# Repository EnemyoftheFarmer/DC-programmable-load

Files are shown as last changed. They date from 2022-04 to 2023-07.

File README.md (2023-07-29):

# Attention
You will need Horizon EDA to view the PCB files.
## Modular Electronic DC Load
#### Motivation
This project will implement a modular 450W DC programmable load. A programmable load is a piece of equipment used to test power supplies, batteries and more. It can also be used to simulate load types or effectively act as a large linear regulator. The motivation came from another project where I needed to measure the efficiency of a boost-buck converter. I needed a high power DC load FAST. This lead to the stupid requirement that I be able to regulate mA and A in the same control loop using no ranging tricks. This had some dumb and interesting consequences in my selection of components.

<figure>
  Bla
  <figcaption>
    Figure 1: DC Load Use Diagram.
    <br>
    An electronic load can be used to test many devices. The most common uses include testing the efficiency of power supplies as well measuring the capacity of batteries. In this example we can see a power supply      being tested for efficiency by measuring input and output power.
  </figcaption>
</figure>

#### Architecture
The architecture is a straightfoward current sink. An opamp drives a MOSFET's gate input until the feedback voltage generated over a current shunt is equal to its set voltage which is derived from a DAC. For the typical DC load functions expected, such as constant power or constant resistance, a microcontroller will calculate the required DAC output voltage.

Three separate PCBs will conprise the system. The logic board will contain all the connectors to the other PCBs and will mount a PICO board for the first revision. Later the RP2040 will be integrated into the logic board. A second board will provide the two voltage rails needed for the DAC and OPAMPs. Power for this board needs to come from an isolated PSU in order to prevent ground loops forming between the system supply and the DUT(device under test). It is yet to determine if it is easier to buy an isolated 12V supply or to use an unisolated 12V and a 12V to 5V on board isolated converter that powers everything except the fans. In the latter case some sort of isolation between the MCU and the 12V fans would need to be added in order to control them. 

Finally, the meat and potatoes of the system is the analog control board. It contains the opamp, DAC, ADC, current shunt, and the MOSFET gate control output. It is intended to be modular such that the system can theorectically be expanded as much as one desires. I have yet to have an idea how to deal with this in software, and in reality there is a practical limit since the DAC is currently SPI controled which means that there needs to be a CS(chip select) pin for each analog control board. Additionally, the ADC has only four adresses it can use, which also limits the expandability. It might be easiest to make the system top out at two or four channels each, and then allow the systems to be slaved to each other over SCPI or something. 

System_Architecture drawio

#### Interface
A rotary encoder is the sole user input for now. A couple of additional hardware buttons would be nice like OUTPUT on/off or mode switching. This area has the most to be decided and is also of lowest priority since it is easy to change without ordering new hardware.

## Component Selection
#### MOSFET
To keep things simple, it uses a single IXYS IXTN200N10L2 Linear MOSFET instead of paralleling many MOSFETs. Most modern MOSFETs are not very well suited to linear operation and many datasheets do not even characterize the DC SOA. One of the reasons is that modern MOSFETs are generally composed of many parallel MOSFETs internally and this can result in hot spotting. The IXYS Linear MOSFETs are specifically built and tested to avoid this. For a one off or hobbyist 
load, it is easier to pay (or sample) the much higher price for a few mosfets that 
are precharacterized and will reliably give you 450W of dissapation. The alternative would be to
buy many opamps and mosfets to divide the load. Assuming that a typical
TO220 package run at a conservative 10W, you would need to make sure to get the price per channel down to around a dollar to make it cost competitive. Definitely achievable, but now 45 TO220s need to be mounted. Additionally, the MOSFET is easily water coolable and already isolated. 
However, I am investigating alternatives since when this project originally started before the silicon shortage, the MOSFET could be bought for a hair under 30$ on mouser. It now costs around 50$... Luckily for the individual it can be sampled so a student or hobbyist may be in luck and won't have to pay a dime if they head over to littlefuse's sample center. It may also be possible to buy directly from littlefuse for a far lower price. One alternative so far is the FDL100N50F, which has a DC SOA of 2.5kW. It seems a little unbelievable to get so much power dissapation in a TO-264 package but who knows. It does have an claimed incredible thermal resistance of just 0.05K/W. The good news is that it only costs 10$ per device and if we run it a very conservative 1/5 of claimed SOA, we still get 500W of power. The biggest downside is no screw terminals and no isolation. The lack of isolation means multiple mosfets cannot be attached to the same heatsink since if one mosfet is on but another off, there is a potential difference between the two. Normally this should not be a problem since the leakage current would be small. However, it would cause a problem when water cooling since electroylsis between the two potential would now take place resulting in corrosion taking place over time. 
#### OPAMP 
The control loop is formed by a very cool ADA4523-1 zero drift opamp. Its 4uV of offset means only 4mA of offset current using a 1 milliohm current shunt. Zero drift is very important since any temperature change will result in the offset current changing noticiably due to the low shunt resistance. It also has a very low 88nV p-p 0.1 to 10Hz input noise which is pretty much all we care about in our DC load anyways. This begs the question why we need a low noise percision op amp for a DC load and the answer is I wanted to be able to set mAs on a 1 milliohm shunt. We need a 1 milliohm shunt because I wanted to sink at least 40A which would mean a 2.5W dissapted in the shunt resistor. An alternative but more expensive part is OPA189.   
#### DAC
My requirement to set mA to A in one range meant that a DAC better than the typical 12 bit DAC is required. I also wanted it to be bipolar in case I needed to set negative voltage to calibrate out the OPAMP offset. In the first revision this accomplished by using a second DAC channel to generate an offset. But since that DAC needed to be replaced anyways, the opportunity was present to simplfy the design and increase laziness. The AD5761R was chosen because it was the cheapest, 16bit, bipolar, TSSOP, and available to sample from Analog Devices DAC.
#### Microcontroller
A raspberry PICO is the brain of the system. The first most important reason is I did not want to use Arduino for once and the documentation for the PICO was very good. Addtionally, its cheap, fast, and wasn't hit by the silicon shortage. I didn't want to integrate an STM32 or the like knowing that no one else could reimplement this system because of supply disruption. 
#### ADC
An ADS1115 was chosen to be the ADC. Its classic, 16 bit and I had it laying around. My only question is if it should be replaced with an ADS1118 so one bus can be eliminated and the system tranisitioned completely to SPI. A modified version of [Elektor Labs](https://github.com/ElektorLabs/ads1115-driver) ADS1115 driver is used to interface with it.
#### Cooling
The cooling system consists primarly out of PC water cooling parts. The radiator is 240mm by 40mm. The resovoir and pump are also just cheap amazon PC water cooling components. In the test runs so far, it seems to be to able to keep the mosfet at around 65 degrees while under 450W of load with the fans at full tilt after the water hits saturation. That puts the junction temp. at ~133 degrees. While still under the TJ_MAX of 150 degrees, it is not clear how this impacts the lifespan of the device, especially considering its high price. Either the cooling capacity needs to be upgraded, the load run less hard, or tests/enquires made to see if its something to worry about. There are tentative plans to attach a thermister to the MOSFET and write some code to make sure that TJ_MAX is never exceeded. 

## PCB Layout and Noise Considerations
Something interesting is that thermal emf had to be considered in the design. Of course it is my fault for expecting to regulate mA and A all in one current shunt but it provided an interesting opportunity to learn. This meant thermal gradients and changes in temperature had to be prevented. The first was to cut an a pair of slots in the PCB so that the heat from the current shunt can not travel to the rest of the components so easily in order to to reduce drift or noise caused by the heat. Then  all critical resistors were aligned perpendicular to the expected thermal gradient since that would mean a much smaller gradient across said resistors. Additionally, there is a method to layout resistors such that thermal emf should cancel. 

thermalemf
 
These last two methods I read about from application note AN1258 from Microchip. Futhermore, in order to avoid Johnson noise, which is thermal noise that is proportional to bandwidth and resistor size, the critical resistors were chosen to be 10 ohms. That puts the resistor noise levels in the 10s of nV for a bandwidth of 1000Hz. This means that so far the theorectical dominant noise source is either the control op amp input noise or the DAC output noise.

## Problems Encountered and Summary so Far
I am quite amazed at how well the load works. Regulating down to 10mA seems no issue which represents a DC level of 10uV. The mA regulation will be implemented soon, but the author was too lazy to modify the software so far. The current is stable down the mA range and noise occurs in the 100s of uA range which would indicate a noise level of 100s of nVs. The current guess is that the op amp input noise, which is 88nV p2p, is the bottleneck. A lower noise but higher drift LT6018 may be tested to see if improvements could be made, even if unnesscary since the requirement was already achieved, as a way to test this theory. The current was measured using the mA range on a Fluke 87V DMM.  

At this stage, the next step is to finalize the analog board layout, complete the logic board layout, and populate the split rail PSU pcb. Additionally, a prototype front panel using an aluminum pcb will be made.
## Prototype Photo





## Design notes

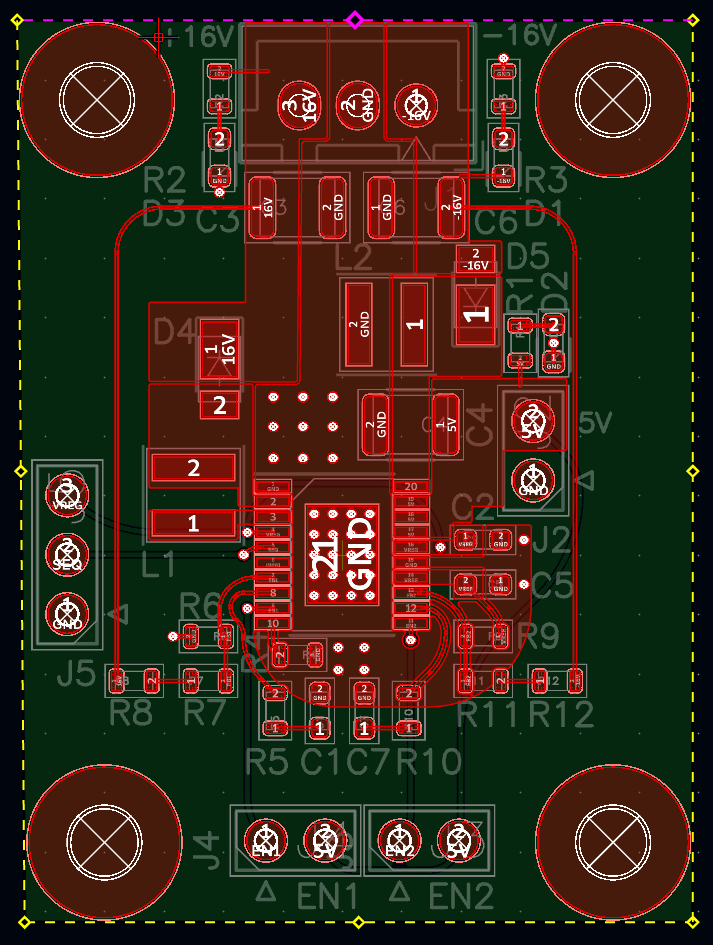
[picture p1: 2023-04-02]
Split_Rail_PSU_PCB.PNG

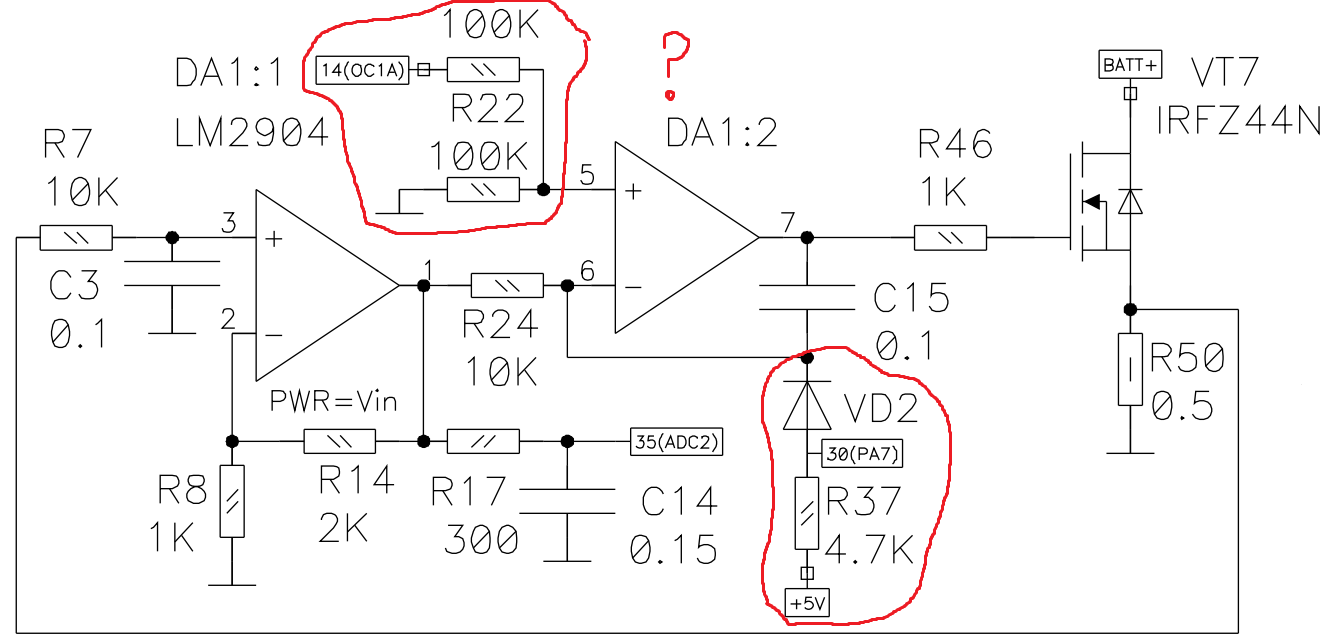
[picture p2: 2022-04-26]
IMAXB6.png

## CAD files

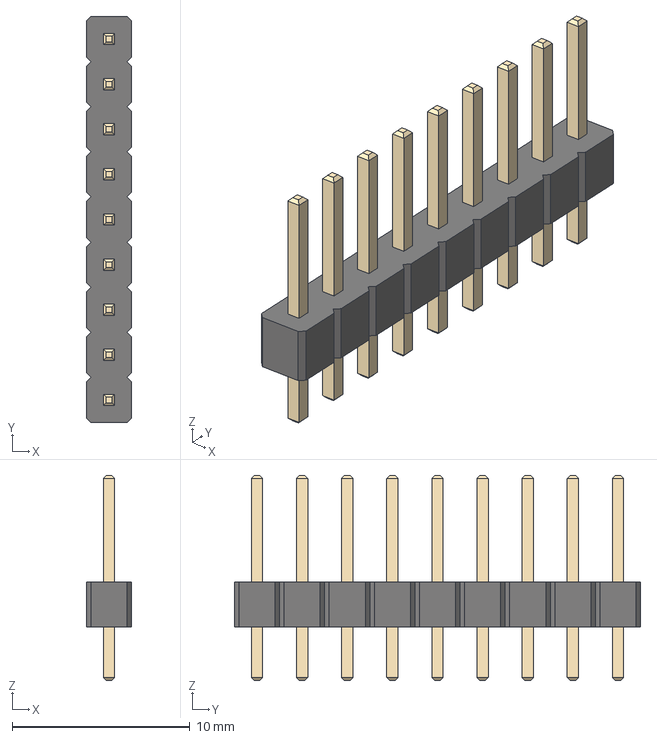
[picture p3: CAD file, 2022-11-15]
Eload-Horizon/Controller/pool/3d_models/cache/6d752bc3-29b3-45df-8cf2-1e3aacefbcc6/3d_models/connector/header/2.54mm/PinHeader_1x09_P2.54mm_Vertical.step
2.54 x 22.9 x 11.5 mm

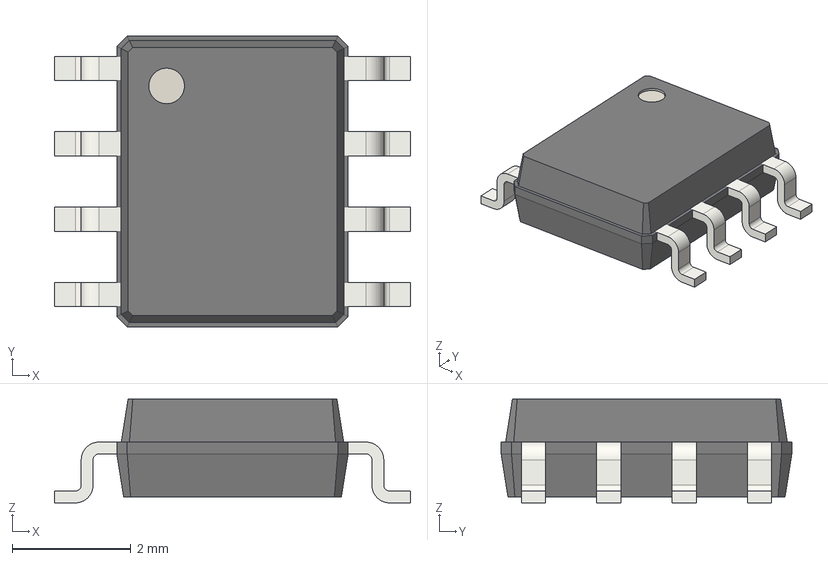
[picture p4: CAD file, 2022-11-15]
Eload-Horizon/Controller/pool/3d_models/cache/6d752bc3-29b3-45df-8cf2-1e3aacefbcc6/3d_models/ic/so/SOIC-8_3.9x4.9mm_P1.27mm.step
6.00 x 4.90 x 1.75 mm

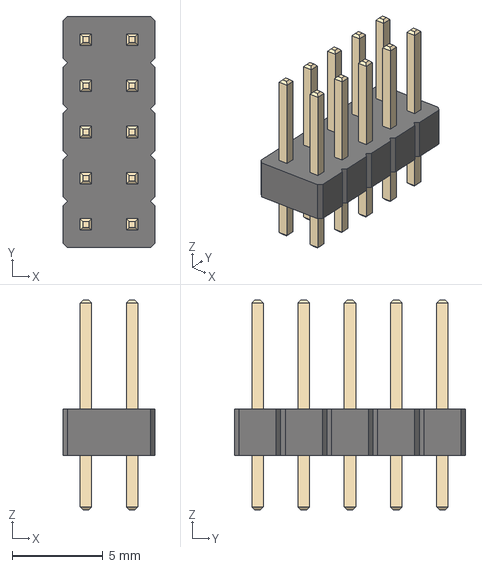
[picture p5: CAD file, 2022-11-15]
Eload-Horizon/Electronic-Load/pool/3d_models/cache/6d752bc3-29b3-45df-8cf2-1e3aacefbcc6/3d_models/connector/header/2.54mm/PinHeader_2x05_P2.54mm_Vertical.step
5.08 x 12.7 x 11.5 mm

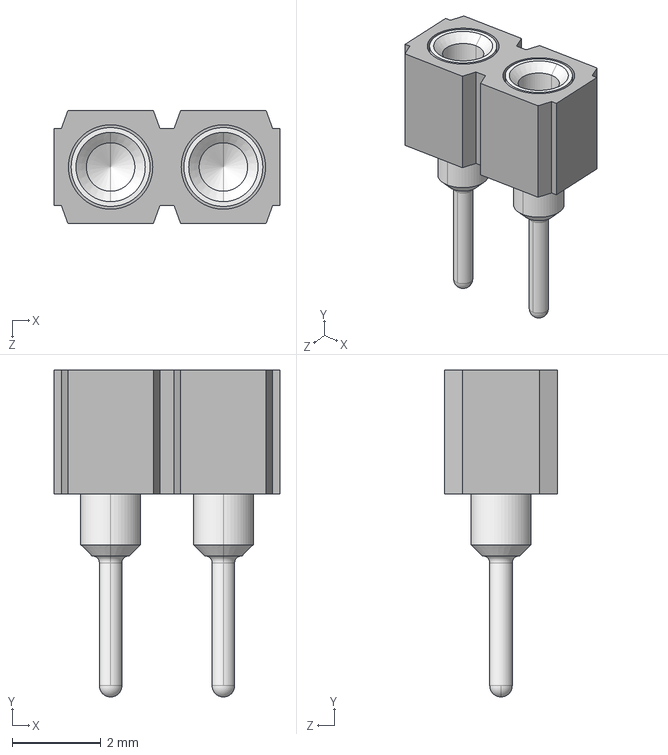
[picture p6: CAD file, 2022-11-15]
Eload-Horizon/Electronic-Load/pool/3d_models/cache/6d752bc3-29b3-45df-8cf2-1e3aacefbcc6/3d_models/custom/Mill-Max/mill-max-310-11-102-41-001000.STEP
5.08 x 7.37 x 2.54 mm
P3XX-11-010-00-000000_P302-11-010-00-000000

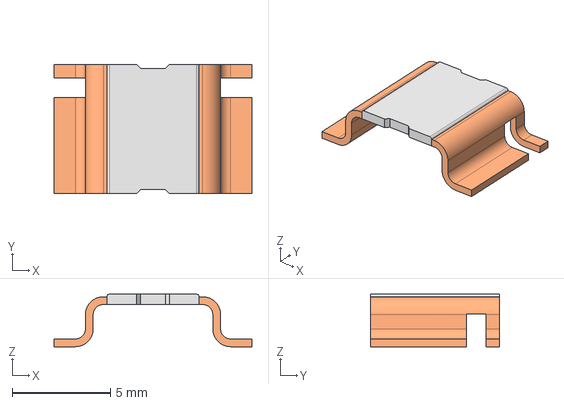
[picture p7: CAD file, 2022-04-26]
Eload-Horizon/Electronic-Load/pool/3d_models/cache/6d752bc3-29b3-45df-8cf2-1e3aacefbcc6/3d_models/custom/Vishay/WSLP4026 (0.001).stp
10.1 x 6.60 x 2.68 mm

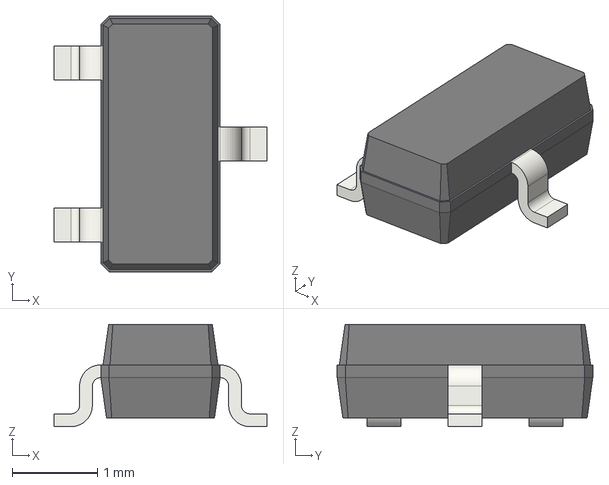
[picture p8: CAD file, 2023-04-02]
Eload-Horizon/Electronic-Load/pool/3d_models/cache/6d752bc3-29b3-45df-8cf2-1e3aacefbcc6/3d_models/ic/so/SOT-23.step
2.50 x 3.00 x 1.20 mm

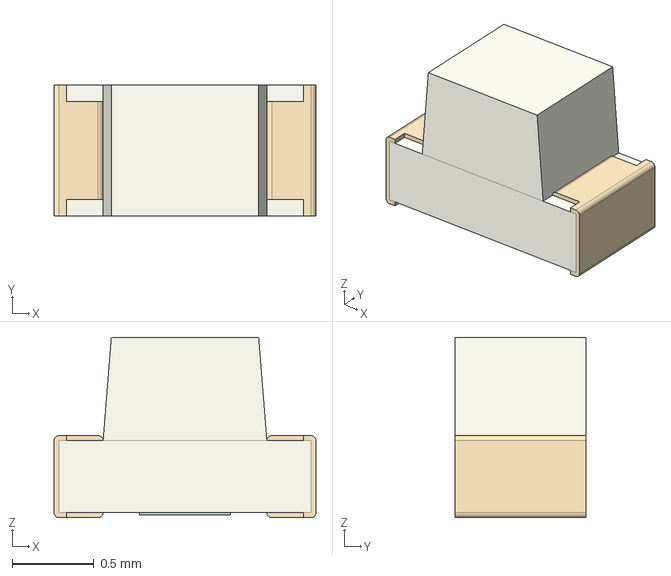
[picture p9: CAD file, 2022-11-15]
Eload-Horizon/Electronic-Load/pool/3d_models/cache/6d752bc3-29b3-45df-8cf2-1e3aacefbcc6/3d_models/opto/LED_0603_1608Metric.step
1.60 x 0.8 x 1.10 mm

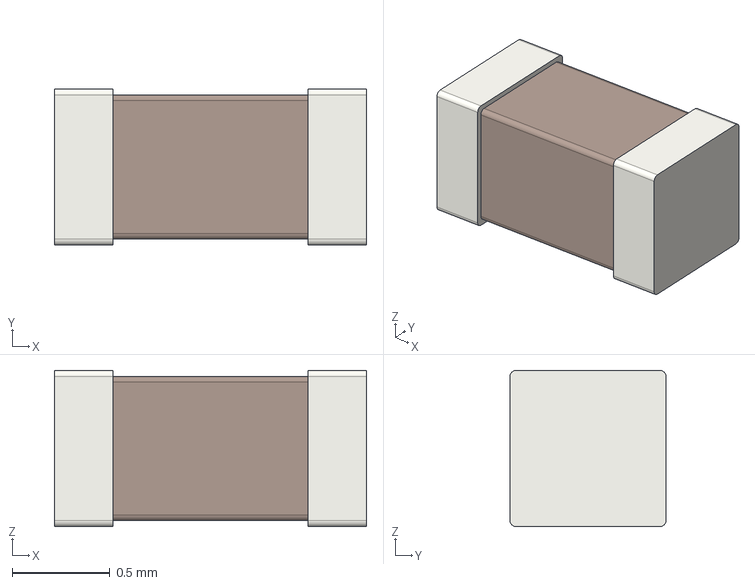
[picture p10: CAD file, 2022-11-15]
Eload-Horizon/Electronic-Load/pool/3d_models/cache/6d752bc3-29b3-45df-8cf2-1e3aacefbcc6/3d_models/passive/capacitor/C_0603_1608Metric.step
1.60 x 0.8 x 0.8 mm

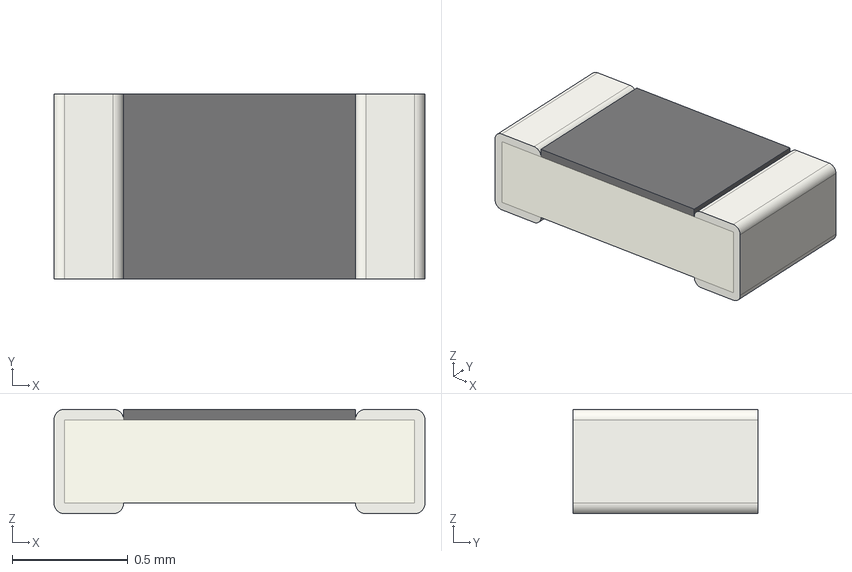
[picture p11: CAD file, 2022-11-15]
Eload-Horizon/Electronic-Load/pool/3d_models/cache/6d752bc3-29b3-45df-8cf2-1e3aacefbcc6/3d_models/passive/resistor/R_0603_1608Metric.step
1.60 x 0.8 x 0.45 mm

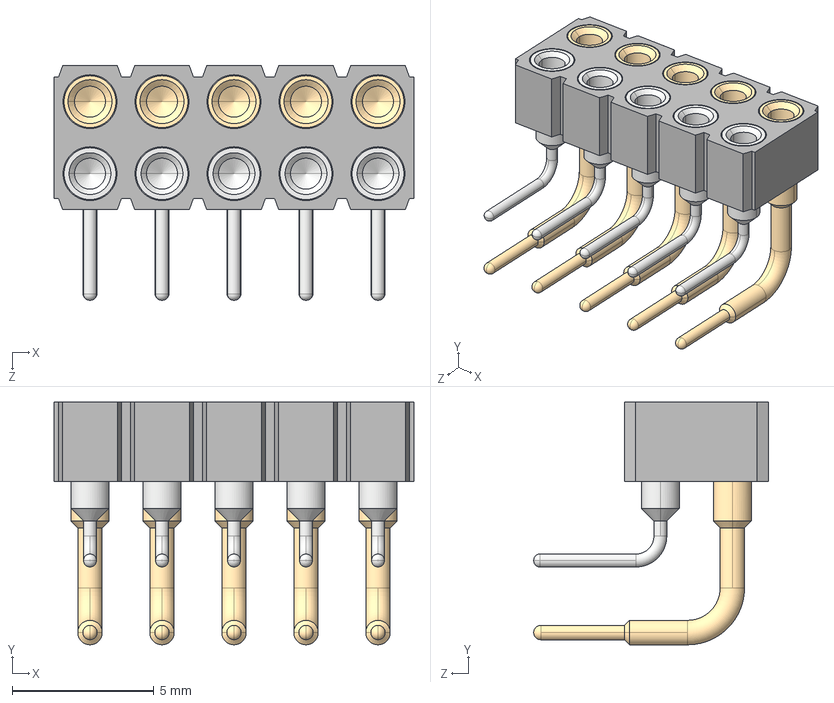
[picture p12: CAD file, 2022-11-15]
Eload-Horizon/Electronic-Load/pool/3d_models/Mill-Max/mill-max-499-13-210-10-003000.STEP
12.7 x 8.56 x 8.28 mm
P4XX-21-010-00-000000_P410-21-010-00-000000

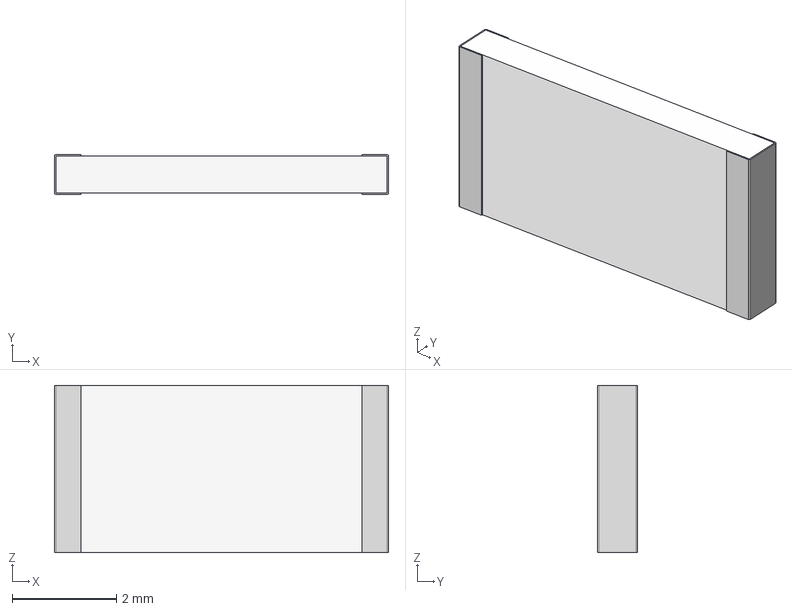
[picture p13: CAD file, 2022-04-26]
Eload-Horizon/Electronic-Load/pool/3d_models/Vishay/thjp_3dmodels/THJP2512A.stp
6.40 x 0.762 x 3.20 mm

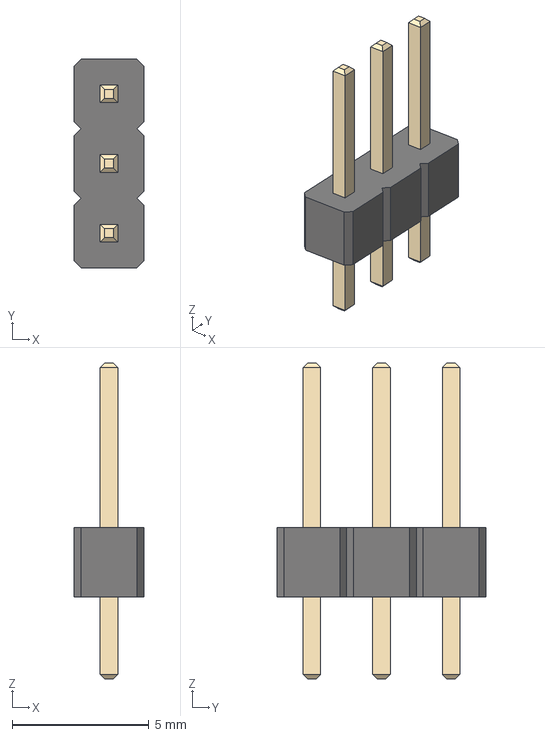
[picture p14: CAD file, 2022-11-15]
Eload-Horizon/Split-Rail-Power-Supply/pool/3d_models/cache/6d752bc3-29b3-45df-8cf2-1e3aacefbcc6/3d_models/connector/header/2.54mm/PinHeader_1x03_P2.54mm_Vertical.step
2.54 x 7.62 x 11.5 mm

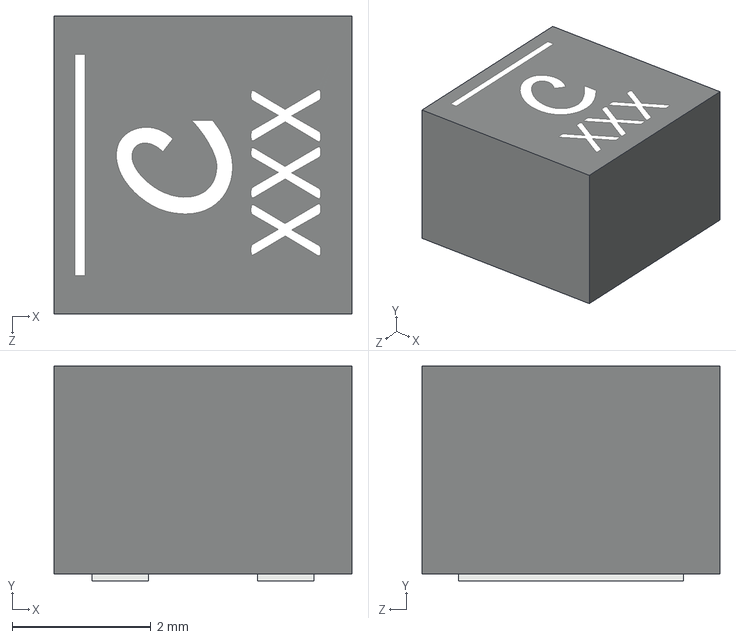
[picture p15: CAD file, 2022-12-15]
Eload-Horizon/Split-Rail-Power-Supply/pool/3d_models/cache/6d752bc3-29b3-45df-8cf2-1e3aacefbcc6/3d_models/custom/Coilcraft/Coilcraft-XGL4030.step
4.30 x 3.10 x 4.30 mm

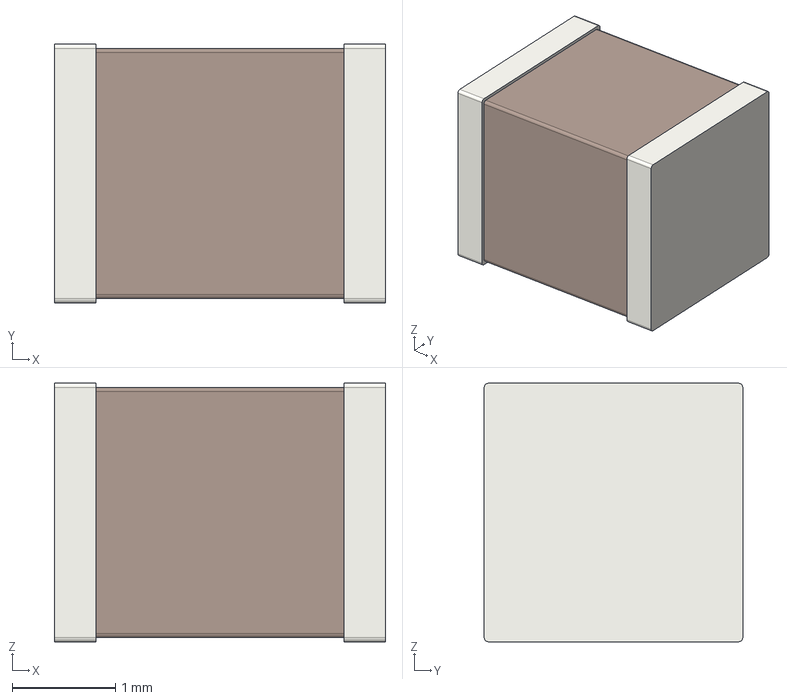
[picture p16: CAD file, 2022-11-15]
Eload-Horizon/Split-Rail-Power-Supply/pool/3d_models/cache/6d752bc3-29b3-45df-8cf2-1e3aacefbcc6/3d_models/passive/capacitor/C_1210_3225Metric.step
3.20 x 2.50 x 2.50 mm

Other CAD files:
Eload-Horizon/Controller/pool/3d_models/cache/6d752bc3-29b3-45df-8cf2-1e3aacefbcc6/3d_models/connector/header/2.54mm/PinHeader_1x20_P2.54mm_Vertical.step
Eload-Horizon/Electronic-Load/pool/3d_models/cache/6d752bc3-29b3-45df-8cf2-1e3aacefbcc6/3d_models/connector/header/2.54mm/PinHeader_2x06_P2.54mm_Vertical.step
Eload-Horizon/Controller/pool/3d_models/cache/6d752bc3-29b3-45df-8cf2-1e3aacefbcc6/3d_models/connector/header/2.54mm/PinHeader_1x02_P2.54mm_Vertical.step
Eload-Horizon/Controller/pool/3d_models/cache/6d752bc3-29b3-45df-8cf2-1e3aacefbcc6/3d_models/connector/header/2.54mm/PinHeader_1x04_P2.54mm_Vertical.step
Eload-Horizon/Electronic-Load/pool/3d_models/Mill-Max/mill-max-380-10-102-00-001000.STEP
Eload-Horizon/Electronic-Load/pool/3d_models/Vishay/CP00010...3.STEP
Eload-Horizon/Electronic-Load/pool/3d_models/Vishay/CP00015...3.STEP
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

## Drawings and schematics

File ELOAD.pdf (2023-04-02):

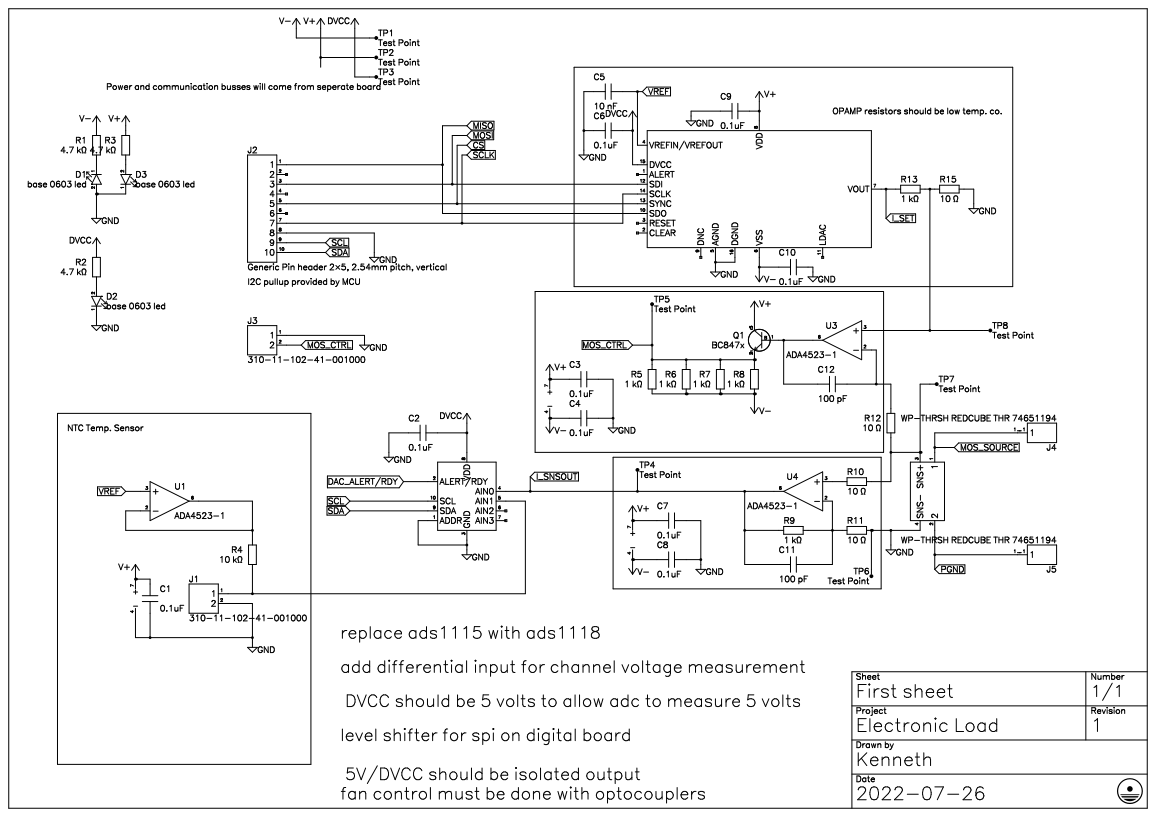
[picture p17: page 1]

Power and communication busses will come from seperate board

OPAMP resistors should be low temp. co.

WP-THRSH REDCUBE THR 74651194

replace ads1115 with ads1118
add differential input for channel voltage measurement
DVCC should be 5 volts to allow adc to measure 5 volts
level shifter for spi on digital board
5V/DVCC should be isolated output
fan control must be done with optocouplers
alert adc, spi for adc

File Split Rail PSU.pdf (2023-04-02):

# 5V to +/- 16V Power Status LEDs

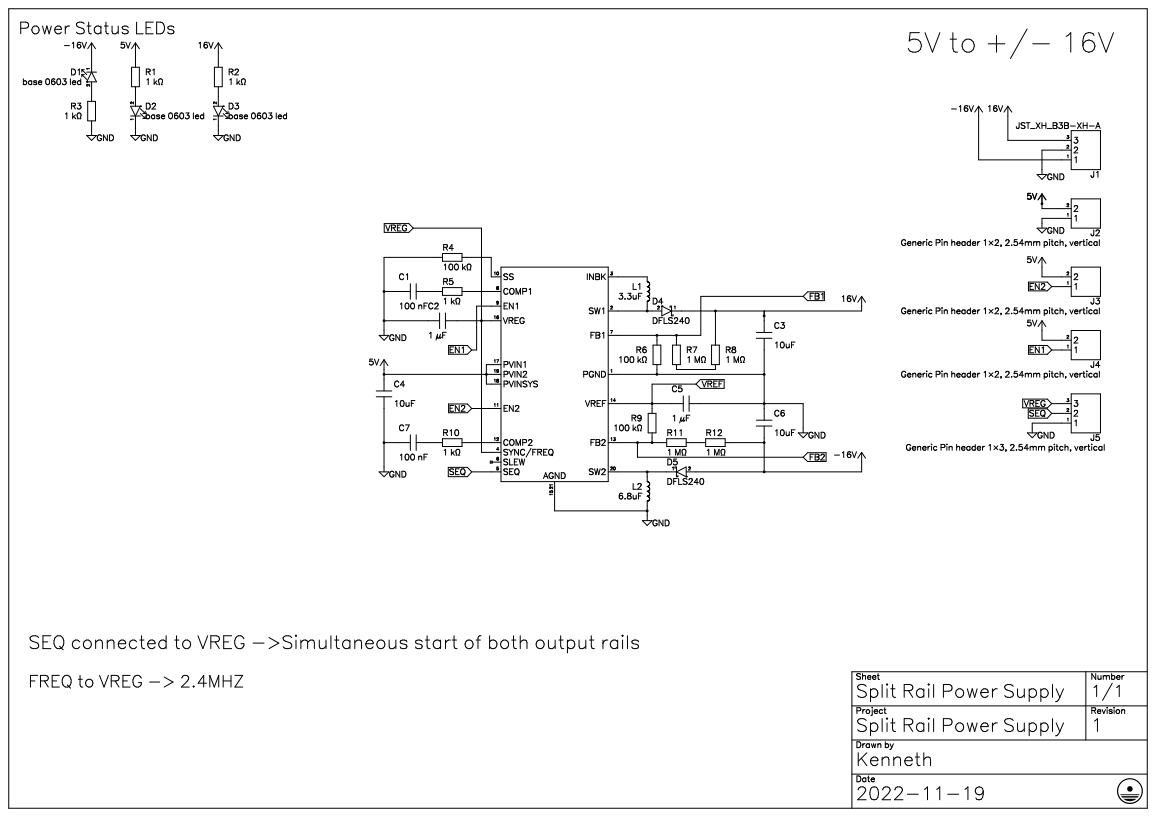
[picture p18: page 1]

Generic Pin header 1×2, 2.54mm pitch, vertical

Generic Pin header 1×3, 2.54mm pitch, vertical

SEQ connected to VREG ->Simultaneous start of both output rails
FREQ to VREG -> 2.4MHZ

Split Rail Power Supply
Split Rail Power Supply | 1

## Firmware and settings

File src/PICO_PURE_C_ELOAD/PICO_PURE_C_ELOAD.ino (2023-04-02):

#include "pico/stdlib.h"
#include "hardware/spi.h"
#include "hardware/i2c.h"
#include "hardware/gpio.h"
#include <U8g2lib.h>
#include <MUIU8g2.h>
#include "ads1x1x.h"


/* Input Shift Register Commands */
#define CMD_NOP                 0x0
#define CMD_WR_TO_INPUT_REG     0x1
#define CMD_UPDATE_DAC_REG      0x2    
#define CMD_WR_UPDATE_DAC_REG   0x3    //updates the dac output voltage
#define CMD_WR_CTRL_REG         0x4    //configures dac settings
#define CMD_NOP_ALT_1           0x5
#define CMD_NOP_ALT_2           0x6
#define CMD_SW_DATA_RESET       0x7
#define CMD_RESERVED            0x8
#define CMD_DIS_DAISY_CHAIN     0x9
#define CMD_RD_INPUT_REG        0xA
#define CMD_RD_DAC_REG          0xB
#define CMD_RD_CTRL_REG         0xC
#define CMD_NOP_ALT_3           0xD
#define CMD_NOP_ALT_4           0xE
#define CMD_SW_FULL_RESET       0xF

//menu options
#define MAIN_MENU 1
#define CONSTANT_CURRENT 2
#define CONSTANT_POWER 3
#define CONSTANT_RESISTANCE 4

//SPI pins
#define RESET_PIN 22
#define DC_PIN 21
#define CS_DISPLAY 20
#define CS_ADC 17
#define MISO 16
#define SCLK 18
#define MOSI 19

//input pins
#define SELECT_PIN 0  //used for selecting fields on the display
#define ROTARY_CH_A 14
#define ROTARY_CH_B 15

//encoder count
volatile int COUNT = 0;
int LASTCOUNT = 0;

uint8_t current_user_input[4];
const float max_allowed_dac_voltage = 4;
float measured_current = 0;

//a structure which will contain all the data for one display
u8g2_t u8g2; 
//a structure which will contain all the data for the UI
mui_t ui;

ADS1x1x_config_t adc;

fds_t fds_data[] = 
//Main Menu
MUI_FORM(1)
MUI_STYLE(1)
MUI_LABEL(1, 10, "MAIN MENU")
MUI_XYAT("G0", 1, 25, 2, "Constant Current")
MUI_XYAT("G0", 1, 37, 3, "Constant Power")
MUI_XYAT("G0", 1, 49, 4, "Constant Resistance")

MUI_FORM(2)
MUI_STYLE(3)
MUI_XYAT("G1", 121, 16, 1, "CC")
MUI_LABEL(83, 16, "Mode:")
MUI_LABEL(0, 60, "Set")
MUI_LABEL(63, 60, "A")
MUI_STYLE(1)
MUI_XY("N0", 21, 60)
MUI_XY("N1", 31, 60)  
MUI_LABEL(40, 60, ".")
MUI_XY("N2", 43, 60) 
MUI_XY("N3", 53, 60) 

MUI_FORM(3)
MUI_STYLE(1)
MUI_LABEL(1, 10, "Constant Power")
MUI_XYAT("G1", 100, 55, 1, "EXIT")

MUI_FORM(4)
MUI_STYLE(1)
MUI_LABEL(1, 10, "Constant Resistance")
MUI_XYAT("G1", 110, 55, 1, "EXIT")
;

muif_t muif_list[] = {  
MUIF_U8G2_LABEL(),
MUIF_BUTTON("G0", mui_u8g2_btn_goto_w1_pi),
MUIF_BUTTON("G1", mui_u8g2_btn_goto_wm_fi),
MUIF_U8G2_U8_MIN_MAX("N0", &current_user_input[0], 0, 9, mui_u8g2_u8_min_max_wm_mud_pf), //input field for current set
MUIF_U8G2_U8_MIN_MAX("N1", &current_user_input[1], 0, 9, mui_u8g2_u8_min_max_wm_mud_pf), //input field for current set
MUIF_U8G2_U8_MIN_MAX("N2", &current_user_input[2], 0, 9, mui_u8g2_u8_min_max_wm_mud_pf), //input field for current set
MUIF_U8G2_U8_MIN_MAX("N3", &current_user_input[3], 0, 9, mui_u8g2_u8_min_max_wm_mud_pf), //input field for current set
MUIF_U8G2_FONT_STYLE(0, u8g2_font_squeezed_b6_tr),
MUIF_U8G2_FONT_STYLE(1, u8g2_font_crox1hb_tf),
MUIF_U8G2_FONT_STYLE(2, u8g2_font_profont10_tf),
MUIF_U8G2_FONT_STYLE(3, u8g2_font_profont12_tf),

};


void setup(){
  //Initialize CS pin and set to high 
  gpio_init(CS_ADC);
  gpio_set_dir(CS_ADC, GPIO_OUT);
  gpio_init(CS_DISPLAY);
  gpio_set_dir(CS_DISPLAY, GPIO_OUT);
  gpio_init(DC_PIN);
  gpio_set_dir(DC_PIN, GPIO_OUT);
  gpio_init(RESET_PIN);
  gpio_set_dir(RESET_PIN, GPIO_OUT);
  gpio_put(CS_ADC, 1);

  gpio_init(SELECT_PIN);
  gpio_set_dir(SELECT_PIN, GPIO_IN);
  gpio_pull_up(SELECT_PIN);
  //enable interrupts
  gpio_set_irq_enabled_with_callback(SELECT_PIN, GPIO_IRQ_EDGE_FALL, 1, isr_handler);  

  gpio_init(ROTARY_CH_A);
  gpio_init(ROTARY_CH_B);
  gpio_set_dir(ROTARY_CH_A, GPIO_IN);
  gpio_set_dir(ROTARY_CH_B, GPIO_IN);
  gpio_set_pulls(ROTARY_CH_A,1,0);
  gpio_set_pulls(ROTARY_CH_B,1,0);

  //enable interrupt for channel A of the rotary encoder
  gpio_set_irq_enabled(ROTARY_CH_A, GPIO_IRQ_EDGE_RISE, 1);  
  gpio_add_raw_irq_handler(ROTARY_CH_A, rotary_callback);
  
  //configure pins to be ready for SPI 
  gpio_set_function(MOSI, GPIO_FUNC_SPI);
  gpio_set_function(MISO, GPIO_FUNC_SPI);
  gpio_set_function(SCLK, GPIO_FUNC_SPI);

  //configure pins to be ready for i2c
  gpio_set_function(PICO_DEFAULT_I2C_SDA_PIN, GPIO_FUNC_I2C);
  gpio_set_function(PICO_DEFAULT_I2C_SCL_PIN, GPIO_FUNC_I2C);
  gpio_pull_up(PICO_DEFAULT_I2C_SDA_PIN);
  gpio_pull_up(PICO_DEFAULT_I2C_SCL_PIN);

  //initialize i2c hardware
  i2c_init(i2c_default, 100 * 1000);

  //initialize spi hardware
  spi_init(spi0, 1000000); //initialize spi hardware
  spi_set_format(spi0, 8, SPI_CPOL_1, SPI_CPHA_0, SPI_MSB_FIRST); //THIS LINE IS SUPER IMPORTANT: WILL NOT WORK OTHERWISE

  //update the ad5761r CMD register with desired configuration settings
  ad5761r_set_configuration();

  //setup u8g2 for our specific display
  u8g2_Setup_ssd1309_128x64_noname0_f(&u8g2, U8G2_R2, u8x8_byte_pico_hw_spi, u8x8_gpio_and_delay_pico); 

  u8g2_InitDisplay(&u8g2); // send init sequence to the display, display is in sleep mode after this,
  u8g2_SetPowerSave(&u8g2, 0); // wake up display
  //u8g2_SetFont(&u8g2, u8g2_font_6x12_tr);

  mui_Init(&ui, &u8g2, fds_data, muif_list, sizeof(muif_list)/sizeof(muif_t));
  mui_GotoForm(&ui, 2, 0);
  mui_Draw(&ui);
  u8g2_SendBuffer(&u8g2);
  u8g2_ClearBuffer(&u8g2);
  Serial.begin(9600);

  ADS1x1x_init(&adc, ADS1115, ADS1x1x_I2C_ADDRESS_ADDR_TO_GND, MUX_SINGLE_0, PGA_512);
  ADS1x1x_set_mode(&adc, MODE_CONTINUOUS);
  ADS1x1x_set_data_rate(&adc, DATA_RATE_ADS111x_16);

  COUNT = 0;
}

void loop(){
  //boot screen
  float voltage_request = current_user_input_to_dac_voltage(get_input(current_user_input[0], current_user_input[1], current_user_input[2], current_user_input[3]), 0.0001);
  //crude current and temp measurements
  ADS1x1x_set_multiplexer(&adc,(ADS1x1x_mux_t)MUX_SINGLE_0);
  ADS1x1x_start_conversion(&adc);
  busy_wait_ms(64);
  measured_current = ((double)ADS1x1x_read(&adc)*512)/(32768*11); //11 stems from the noninverting amplifiers gain
  //end of crudeness
  switch(mui_GetCurrentFormId(&ui)){ //move into the logic for the present menu option
    case CONSTANT_CURRENT:
    //the behavoir expected for a constant current loop is:
    //-current should be held constant regardless of input voltage
    //-the setting of current should have an upper bound as to prevent damage to the mosfet(in regards to specs. and temp)
    //todo: get voltage/current reading, add total power consumed option, timer, undervoltage limit
      if(ui.is_mud){ //check if a digit is selected -> input won't change if none are selected
        if(COUNT > LASTCOUNT){
          mui_NextField(&ui);
          voltage_request = current_user_input_to_dac_voltage(get_input(current_user_input[0], current_user_input[1], current_user_input[2], current_user_input[3]), 0.0001);
          //if the incrementation of the the digit on which the cursor is focused is larger than max current...
          if(voltage_request > max_allowed_dac_voltage){ //replace with max current criteria
            current_user_input[0] = 4;
            current_user_input[1] = 0;
            current_user_input[2] = 0;
            current_user_input[3] = 0;
          }
        }
        else if(COUNT < LASTCOUNT){
          mui_PrevField(&ui);
          voltage_request = current_user_input_to_dac_voltage(get_input(current_user_input[0], current_user_input[1], current_user_input[2], current_user_input[3]), 0.0001);
          //if the incrementation of the the digit on which the cursor is focused is larger than max current...
          if(voltage_request > max_allowed_dac_voltage){ //replace with max current criteria
            current_user_input[0] = 4;
            current_user_input[1] = 0;
            current_user_input[2] = 0;
            current_user_input[3] = 0;
          }
        }
        ad5761r_output_write(float_to_dac_code(voltage_request, 5, 0));
      }
      else{ //no digit selected
        menu_handle_fields();
      }
      char str[10];
      sprintf(str, "% 07.3f", measured_current);
      u8g2_SetFont(&u8g2, u8g2_font_crox4hb_tf);
      u8g2_DrawStr(&u8g2, 0, 16, str);
      u8g2_DrawStr(&u8g2, 0, 34, str);
      u8g2_SetFont(&u8g2, u8g2_font_profont12_tf);
      u8g2_DrawStr(&u8g2, 70, 16, "V");
      u8g2_DrawStr(&u8g2, 70, 34, "A");
      u8g2_DrawStr(&u8g2, 70, 47, "W");
      u8g2_SetFont(&u8g2, u8g2_font_crox1hb_tf);
      u8g2_DrawStr(&u8g2, 24, 47, str);
      u8g2_SetContrast(&u8g2, 50);
      /*list of good fonts:
      u8g2_font_crox2hb_tf
      u8g2_font_profont22_tf
      */
      break;
    case CONSTANT_POWER:
      //current = POWER_SET/measured_voltage
      break;
    case CONSTANT_RESISTANCE:
      break;
    default: //MAIN_MENU case
      menu_handle_fields();
      break;
  }
  
  LASTCOUNT = COUNT;
  //update the display
  mui_Draw(&ui);
  u8g2_SendBuffer(&u8g2);
  u8g2_ClearBuffer(&u8g2);
}


float get_input(uint8_t d1, uint8_t d2, uint8_t d3, uint8_t d4){
  return d1 * 10000 + d2 * 1000 + d3 * 100 + d4 * 10; //return the input in milliamps
}

float current_user_input_to_dac_voltage(float input, float divider){
  //takes the input given in the form of a requested current and returns a a voltage that the dac should output
  //calibration, resistor dividers and so on should all be included in here 
  //TODO:
  //calibration
  //should current be passed  arround in amps or milliamps????
  return (float)(input*divider);
}

uint16_t float_to_dac_code(float input, float dac_max_output, float dac_min_output){
  //takes the requested dac voltage (after voltage divider) given as a float and maps it to the uint16 voltage code for the dac
  //ex: dac settings are 0V - 5V (0-50mV due to the divider), so we wish to map the range 0 - 5V over a uint16_t -> float_to_dac_code(requested value, 50000, 0);
  //ex2: dac settings are -2.5V - 7.5V (-25mV - 75mV due to the divider) -> float_to_dac_code(requested value, 75000, -25000);
  if(((((input - dac_min_output)*(UINT16_MAX))/(dac_max_output - dac_min_output))) > UINT16_MAX){ //check for overflow
    return UINT16_MAX;
  }
  else if(((((input - dac_min_output)*(UINT16_MAX))/(dac_max_output - dac_min_output))) < 0){ //check for underflow
    return 0; 
  }
  else{ //return based on the mapping formula
    return (((input - dac_min_output)*(UINT16_MAX))/(dac_max_output - dac_min_output));
  }
}

void menu_handle_fields(){ //used to determine what field the rotary encoder selects next
  if(COUNT > LASTCOUNT){
    mui_NextField(&ui);
  }
  else if(COUNT < LASTCOUNT){
    mui_PrevField(&ui);
  }
}









//general interrupt routine handler
void isr_handler(uint gpio, uint32_t events){ 
  if(gpio == SELECT_PIN){
    mui_SendSelect(&ui);
    if(mui_GetCurrentFormId(&ui) == 1){ //if we exited to the main menu, we want the load to stop all current draw
      
      ad5761r_output_write(0);
    }
  }
}

//rotary encoder interrupt handler
void rotary_callback(void){
  if (gpio_get_irq_event_mask(ROTARY_CH_A) & GPIO_IRQ_EDGE_RISE){
    if(gpio_get(ROTARY_CH_B) != gpio_get(ROTARY_CH_A)){
      COUNT ++;
    }
    else{
      COUNT --;
    }
  }
  gpio_acknowledge_irq(ROTARY_CH_A, GPIO_IRQ_EDGE_RISE);
}







void ad5761r_set_configuration(){
  //sets the configuration of the ad5761r 
  uint8_t configuration_data[3];
  configuration_data[0] = CMD_WR_CTRL_REG;
  configuration_data[1] = 0b00000000;
  configuration_data[2] = 0b01100011; 
  spi_set_format(spi0, 8, SPI_CPOL_1, SPI_CPHA_0, SPI_MSB_FIRST);
  gpio_put(CS_ADC,0);
  spi_write_blocking(spi0, configuration_data, 3);
  gpio_put(CS_ADC,1);
}

void ad5761r_output_write(uint16_t current_user_input){
  /*Function to update the output of the ad5761r, parameter is a 16bit integer that is mapped to the output 
  according to the bits set in the configuration register of the ad5761r*/
  //The desired output voltage is a 16 bit number that is sent after sending the update dac register address 
  uint8_t DATA[3];
  DATA[0] = CMD_WR_UPDATE_DAC_REG;
  DATA[1] = (current_user_input >> 8) & 0xFF;
  DATA[2] = (current_user_input >> 0) & 0xFF;
  spi_set_format(spi0, 8, SPI_CPOL_1, SPI_CPHA_0, SPI_MSB_FIRST); 
  gpio_put(CS_ADC, 0);
  spi_write_blocking(spi0, DATA, 3);
  gpio_put(CS_ADC, 1);
}

void ADS1x1x_write_register(uint8_t i2c_address, uint8_t reg, uint16_t value)
{
  uint8_t buffer[3];
  buffer[0] = reg;
  buffer[1] = (uint8_t)(value>>8); 
  buffer[2] = (uint8_t)(value&0xff);
  i2c_write_blocking(i2c0, i2c_address, buffer, 3, 0);
}

uint16_t ADS1x1x_read_register(uint8_t i2c_address, uint8_t reg)
{
  uint8_t data_buffer[2];
  uint8_t reg_buffer[1];
  uint16_t result;
  reg_buffer[0] = reg;
  i2c_write_blocking(i2c0, i2c_address, reg_buffer, 1, 0);
  i2c_read_blocking(i2c0, i2c_address, data_buffer, 2, 0); 		
  result = (uint16_t)data_buffer[0] << 8 | data_buffer[1];
  return result;
}

////U8G2 library porting functions
uint8_t u8x8_gpio_and_delay_pico(u8x8_t *u8x8, uint8_t msg, uint8_t arg_int, void *arg_ptr)
{
  switch(msg){

    case U8X8_MSG_GPIO_AND_DELAY_INIT:	// called once during init phase of u8g2/u8x8
      break;							// can be used to setup pins
    case U8X8_MSG_DELAY_10MICRO:		// delay arg_int * 10 micro seconds
      busy_wait_us(arg_int*10);
      break;
    case U8X8_MSG_DELAY_MILLI:			// delay arg_int * 1 milli second
      busy_wait_ms(arg_int);
      break;
    case U8X8_MSG_DELAY_I2C:				// arg_int is the I2C speed in 100KHz, e.g. 4 = 400 KHz
      busy_wait_us(5);
      break;							// arg_int=1: delay by 5us, arg_int = 4: delay by 1.25us
    case U8X8_MSG_GPIO_CS:				// CS (chip select) pin: Output level in arg_int
      gpio_put(CS_DISPLAY, arg_int);
      break;
    case U8X8_MSG_GPIO_DC:				// DC (data/cmd, A0, register select) pin: Output level in arg_int
      gpio_put(DC_PIN, arg_int);
      break;
    case U8X8_MSG_GPIO_RESET:			// Reset pin: Output level in arg_int
      gpio_put(RESET_PIN, arg_int);
      break;
    case U8X8_MSG_GPIO_I2C_CLOCK:		// arg_int=0: Output low at I2C clock pin
      break;							// arg_int=1: Input dir with pullup high for I2C clock pin
    case U8X8_MSG_GPIO_I2C_DATA:			// arg_int=0: Output low at I2C data pin
      break;							// arg_int=1: Input dir with pullup high for I2C data pin*/
    default:
      u8x8_SetGPIOResult(u8x8, 1);			// default return value
      break;
  }
  return 1;
}

uint8_t u8x8_byte_pico_hw_i2c(u8x8_t *u8x8, uint8_t msg, uint8_t arg_int, void *arg_ptr){
  /* u8g2/u8x8 will never send more than 32 bytes between START_TRANSFER and END_TRANSFER */
  static uint8_t buffer[32];
  static uint8_t buf_idx;
  uint8_t *data;
 
  switch(msg){
    case U8X8_MSG_BYTE_SEND:
      data = (uint8_t *)arg_ptr;      
      while(arg_int > 0){
	    buffer[buf_idx++] = *data;
	    data++;
	    arg_int--;
      }      
      break;
    case U8X8_MSG_BYTE_INIT:
      /* add your custom code to init i2c subsystem */
      break;
    case U8X8_MSG_BYTE_SET_DC:
      /* ignored for i2c */
      break;
    case U8X8_MSG_BYTE_START_TRANSFER:
      buf_idx = 0;
      break;
    case U8X8_MSG_BYTE_END_TRANSFER:
      //i2c_transfer(u8x8_GetI2CAddress(u8x8) >> 1, buf_idx, buffer);
      i2c_write_blocking(i2c_default, u8x8_GetI2CAddress(u8x8) >> 1, buffer, buf_idx, false);
      break;
    default:
      return 0;
  }
  return 1;
}

uint8_t u8x8_byte_pico_hw_spi(u8x8_t *u8x8, uint8_t msg, uint8_t arg_int, void *arg_ptr){ 
  switch(msg){
    case U8X8_MSG_BYTE_SEND:
      spi_write_blocking(spi0, (uint8_t *) arg_ptr, arg_int); 
      break;
    case U8X8_MSG_BYTE_INIT:
      break;
    case U8X8_MSG_BYTE_SET_DC:
      gpio_put(DC_PIN, arg_int);
      break;
    case U8X8_MSG_BYTE_START_TRANSFER:
      switch(u8x8->display_info->spi_mode) {
        case 0: 
          spi_set_format(spi0, 8, SPI_CPOL_0, SPI_CPHA_0, SPI_MSB_FIRST);
          break;
        case 1: 
          spi_set_format(spi0, 8, SPI_CPOL_0, SPI_CPHA_1, SPI_MSB_FIRST);
          break;
        case 2: 
          spi_set_format(spi0, 8, SPI_CPOL_1, SPI_CPHA_0, SPI_MSB_FIRST);
          break;
        case 3: 
          spi_set_format(spi0, 8, SPI_CPOL_1, SPI_CPHA_1, SPI_MSB_FIRST);
          break;
      }
      gpio_put(CS_DISPLAY, LOW);
      break;
    case U8X8_MSG_BYTE_END_TRANSFER:
      gpio_put(CS_DISPLAY, HIGH);
      break;
    default:
      return 0;
  }
  return 1;
}

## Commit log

2021-10-24 PCB
    Added via stitching
2021-10-26 Revision 0
    First Board ordered
2022-11-15 Major
    Pushed the libaries to the correct space
    [2012670005.stp, 2060-451_998-404.stp, 2604-1103.stp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]
2023-04-02 April update
    New layout:
    -VSENSE moved to board
    -PWR leds
    -DVCC should be 5V to allow ADC to measure full range->use I2C level shift
    -paralleled 1K emitter resistors for lower impedance, resuse of existing bom item
    -BC547c -> BC847c
    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
    [LED_0603_1608Metric.step, SOT-23.step]
2023-07-29 Update README.md
    new boards

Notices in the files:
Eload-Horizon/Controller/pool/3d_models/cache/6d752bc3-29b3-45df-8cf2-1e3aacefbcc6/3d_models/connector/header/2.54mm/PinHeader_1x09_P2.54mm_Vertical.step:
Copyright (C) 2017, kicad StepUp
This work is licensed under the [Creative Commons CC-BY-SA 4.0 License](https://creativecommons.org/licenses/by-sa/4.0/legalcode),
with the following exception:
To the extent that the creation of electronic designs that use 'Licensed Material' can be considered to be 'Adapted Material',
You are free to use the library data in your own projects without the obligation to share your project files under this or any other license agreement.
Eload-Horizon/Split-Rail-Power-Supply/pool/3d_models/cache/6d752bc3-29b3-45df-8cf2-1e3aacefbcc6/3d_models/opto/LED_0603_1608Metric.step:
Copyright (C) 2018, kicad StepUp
